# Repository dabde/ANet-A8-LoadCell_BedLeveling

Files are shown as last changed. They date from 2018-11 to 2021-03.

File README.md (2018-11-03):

# Anet A8 LoadCell BedLeveling

## Why?
No Z Sensor offset, just probe with the tip of your nozzle.

## how it's looks

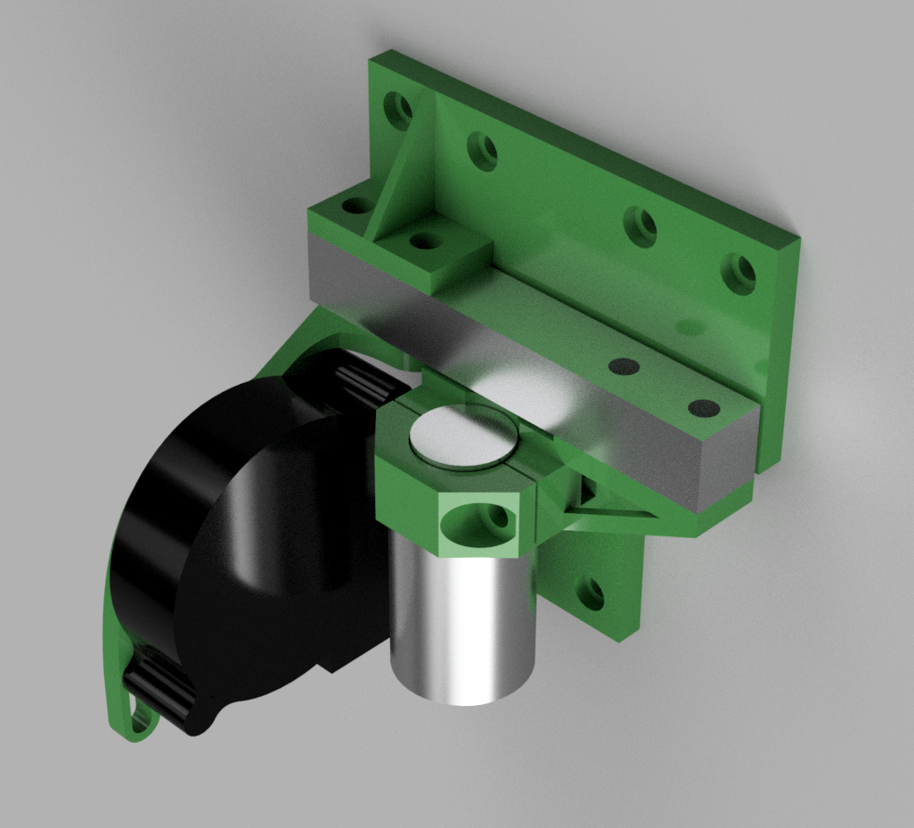
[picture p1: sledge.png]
3d render of model


## Limitation

### HX711
In default, the hx711 is set to send only 10 sps, to upgrade to 80 sps, depends on your module, you need to change an jumper replace an 0 Ohm resistor.

### leveling
HX711 has only a sample rate of 80 sps and need some communication time, related to this, my bed probing runs with an Z speed of only 1ms/s

```gcode
G28 XY; home XY axes
G28 Z; home Z FAST
M203 Z1.00 ;slow speed for z for homing and leveling (slow probe)
G28 Z; home Z SLOW
G29 P2
M203 Z8.00 ; reset Z Speed limit
```

## Good to Know
### 3d model
The 3D model is maybe not the best one yet, the sledge is depends on the LoadCell now wider than usual, this means you need also tweak a little bit your marlin settings for offset of X,Y.

I can't provide my ones, related I have some other tweak from the stock Anet A8 behavior.

### arduino source code
In the sourcecode I have currently set static to trigger at an LoadCell Value over 20, if your setup variates, you need maybe tweak this line
```
  if (i<-20) {
```

### trigger
In the source code, I also set the onboard LED, so you can check visual if your LoadCell reach the force.

## what you need

1. LoadCell (I have just take a 5kg one) (~2€)
1. HX711 LoadCell Amplifier (sometimes already in the Loadcell included)
1. Arduino (i have take just an arduino nano clone ~4€)
1. printed 3d models from the (./models) directory (~2€)
1. some wires

**cost: around 8€**

## How to wire

```
ANet Z Input (5V)     <--> arduino VCC
ANet Z Input (GND)    <--> arduino GND
ANet Z Input (SIGNAL) <--> arduino PIN 4
```

```
HX711 (GND) <--> arduino GNX
HX711 (VCC) <--> arduino VCC
HX711 (DT)  <--> arduino PIN 3
HX711 (SCK) <--> arduino PIN 2
```

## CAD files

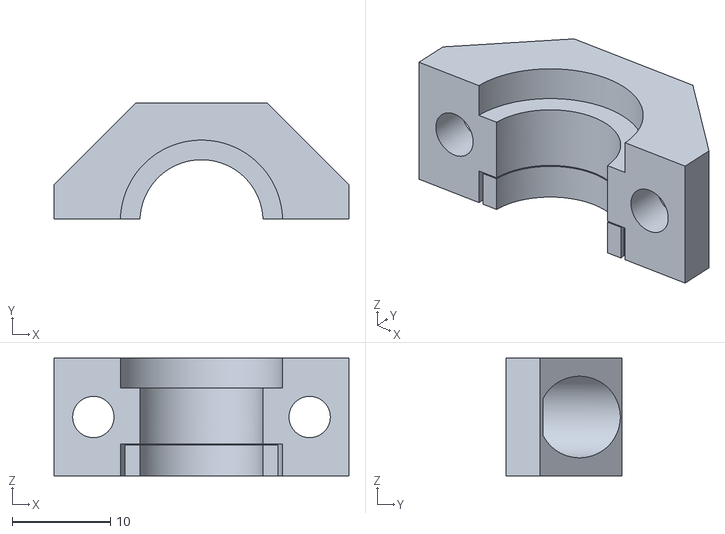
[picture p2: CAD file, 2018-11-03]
models/hotend_holder_part_2_custom_support.stl
30.0 x 11.8 x 12.0

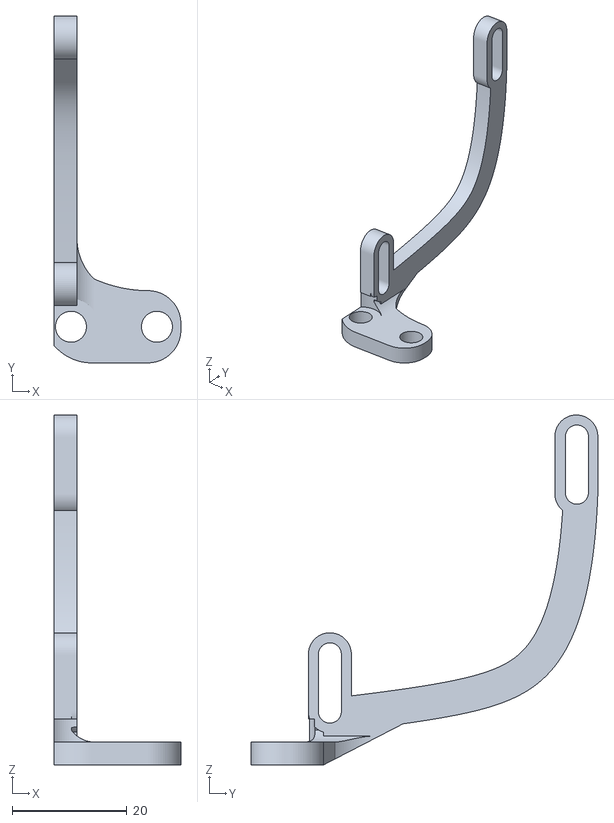
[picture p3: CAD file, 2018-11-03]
models/sledge_fan_mount.stl
22.1 x 60.5 x 61.1

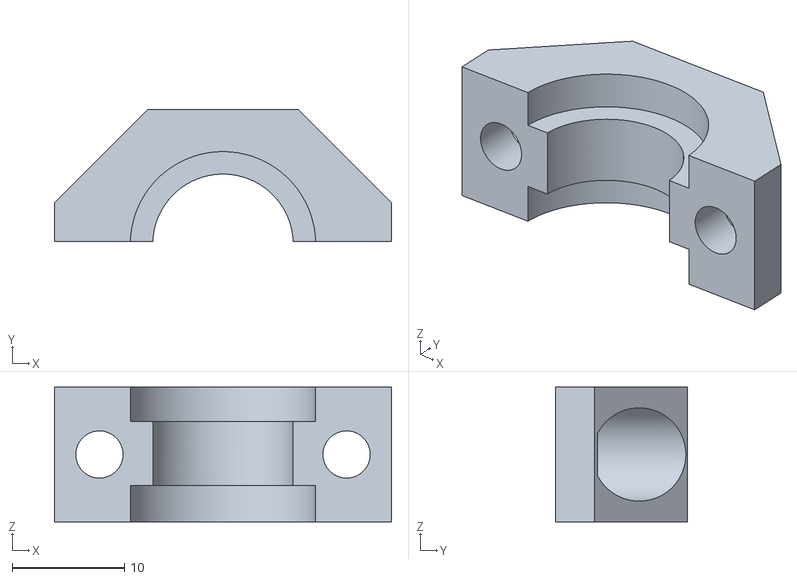
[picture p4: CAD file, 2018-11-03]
models/hotend_holder_part_2_no_support.stl
30.0 x 11.8 x 12.0

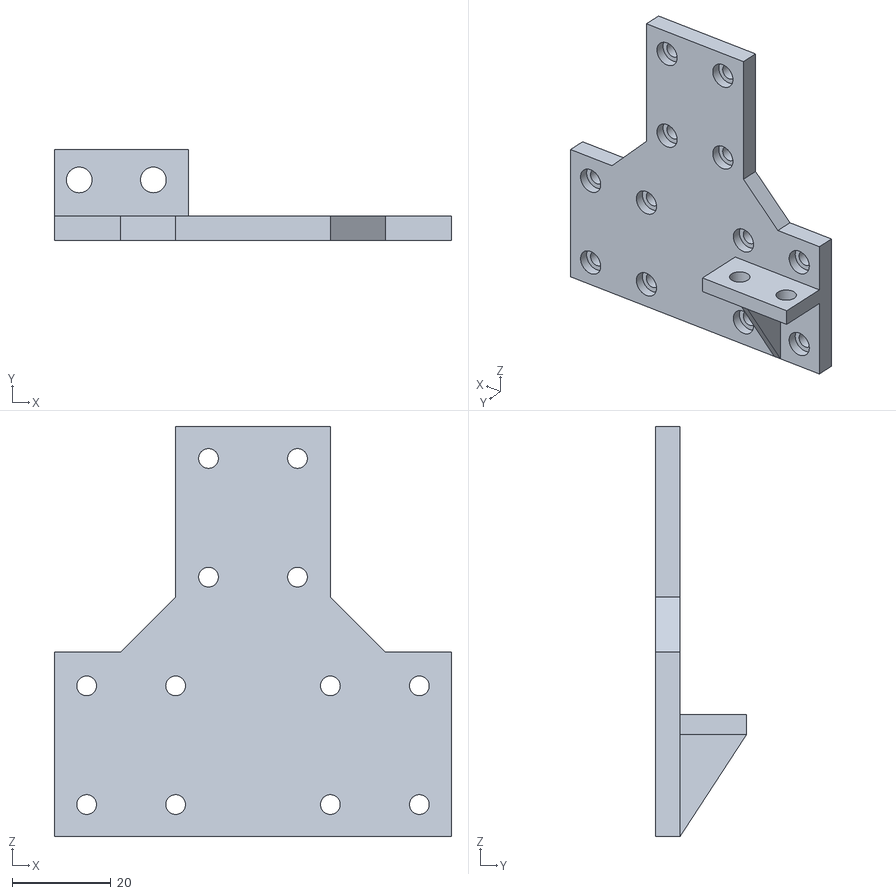
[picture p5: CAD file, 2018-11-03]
models/sledge_mount.stl
80.3 x 18.5 x 83.0

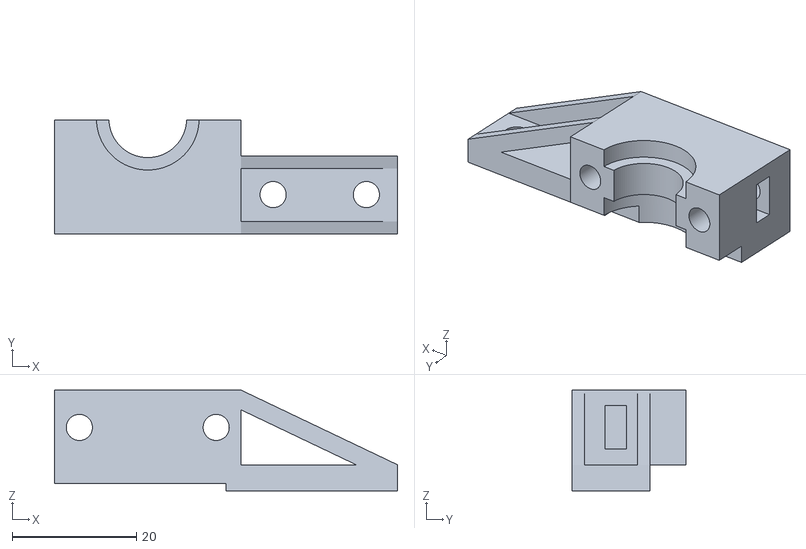
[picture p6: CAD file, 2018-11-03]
models/hotend_holder_part_1_no_support.stl
55.2 x 18.2 x 16.2

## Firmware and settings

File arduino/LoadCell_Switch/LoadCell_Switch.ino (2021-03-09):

#include <HX711_ADC.h>
#include <movingAvg.h>

HX711_ADC LoadCell(2, 3);
movingAvg mySensor(10);

#define ANETA8_OUT 5

void setup() {
  pinMode(LED_BUILTIN, OUTPUT);
  pinMode(ANETA8_OUT, OUTPUT);
  Serial.begin(57600);
  Serial.println("Wait...");
  LoadCell.begin(64);
  long stabilisingtime = 25; // tare preciscion can be improved by adding a few seconds of stabilising time
  LoadCell.start(stabilisingtime);
  LoadCell.setCalFactor(696.0); // user set calibration factor (float)
  mySensor.begin();
  Serial.println("Startup + tare is complete");
}

void loop() {
  LoadCell.update();
  int LoadCellRead = round(LoadCell.getData()*1000);
  mySensor.reading(LoadCellRead);
  
  if ((LoadCellRead-mySensor.getAvg())<-2000) {
    digitalWrite(LED_BUILTIN, LOW);
    digitalWrite(ANETA8_OUT, LOW);
  } else {
    digitalWrite(LED_BUILTIN, HIGH);
    digitalWrite(ANETA8_OUT, HIGH);
  }
  
  Serial.print(LoadCellRead);
  Serial.print("\t");
  Serial.print(mySensor.getAvg());
  Serial.print("\t");
  Serial.println(LoadCellRead-mySensor.getAvg());
}

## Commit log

2018-11-03 init project
    init project
    [hotend_holder_part_1_no_support.stl, hotend_holder_part_2_custom_support.stl, hotend_holder_part_2_no_support.stl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]
2018-11-03 Fix Readme, LED OnBoard triggering
